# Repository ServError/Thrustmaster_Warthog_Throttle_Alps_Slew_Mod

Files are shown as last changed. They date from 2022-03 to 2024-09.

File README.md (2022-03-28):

# Thrustmaster Warthog Throttle Alps Slew Mod

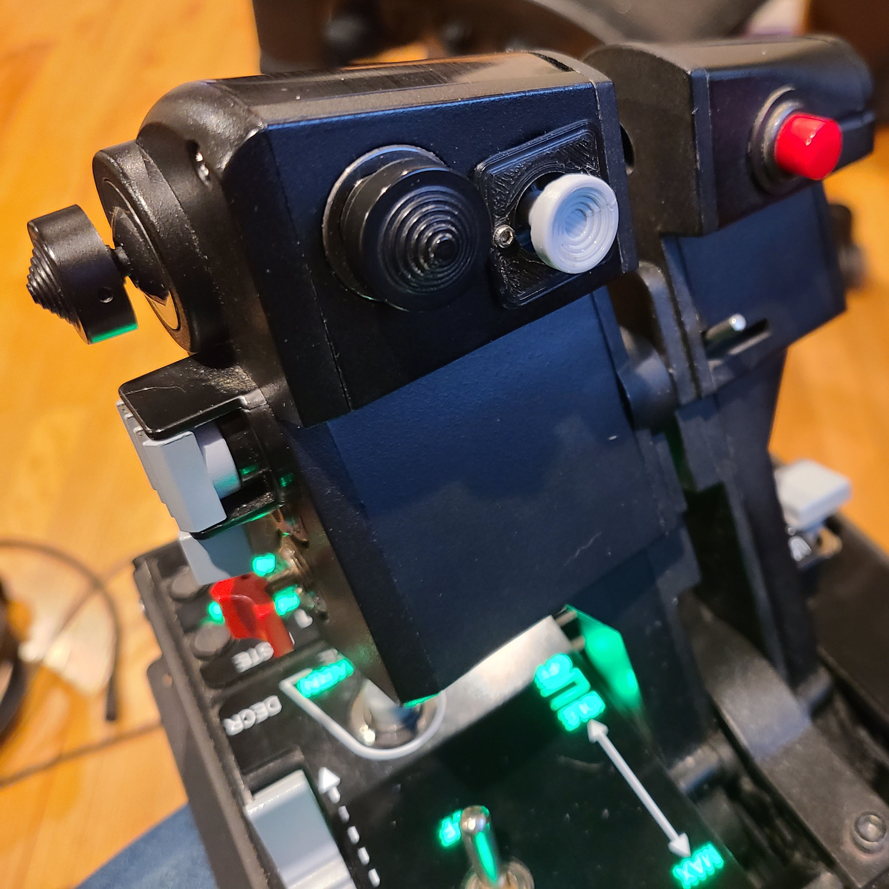
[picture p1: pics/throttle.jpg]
Mod


This repository houses the Thrustmaster Warthog Throttle Alps Slew Mod, an open source alternative to Thrustmaster's cheap slew joystick originally provided on the throttle.

## Is this Delta Sim's mod?

Nope, this was my 2022 mechanical, electrical, and software engineering practice project. Though the [Instructable](https://www.instructables.com/Thrustmaster-Warthog-Slew-Sensor-I2C-Upgrade/) provided a good sanity check, I started from scratch and did my own logic analysis, etc.

### Why does it look similar?

It's a bare minimum set of components fitting into a tight, keyed space while being compatible with an existing product, the only way it was going to look different was if I went out of my way to do something weird.

## How can I build it?

Let me start by stating the following: This project is mostly educational. Given the amount of parts and work it takes to build one of these, you should heavily consider buying [Delta Sim's slew mod](https://deltasimelectronics.com/products/thumbstick-slew-sensor-adapter) if you're just looking to mod your throttle and fly. Since (last I checked) it uses the same microcontroller as this project, you could even potentially switch to the firmware in this repository if you believed it to be beneficial.

### I'm still here

Alright then, You'll need to handle

- [The PCB](pcb/)
- [The Plastics](plastic/)
- [The Firmware](firmware/)

### Building

- Once the PCB is complete, program it with the firmware.

- Take 4 1.6x4mm screws and connect the frame to the PCB and take care to orient the notch correctly (see photo in plastics section).

- Connect the wire to the header.

- Unplug and pop out the original slew stick by pressing in the two clasps while pulling it outward.

- Insert the new unit into the throttle. Use notch on bottom of frame to align with notch in opening.

- Use 2 remaining screws to screw cover to frame. Do not overtighten! Screw in a good amount then install the stick.

- Check stick clearance with 2 screws and continue screwing until just barely clearing the stick.

- Connect the wire to the mainboard.

- Reassemble throttle while taking extreme care not to pinch cables between the plastic posts and throttle body. Feel free to wrap longer wires around the posts before assembling Use flashlight to triple verify clearance on other side before reinstall large screws.

- Plug in throttle and download [calibration tool with modified deadzone values](https://drive.google.com/file/d/1Ltr-QlWskVfA8-Oxs-A-aUs4HPpge5iv/view?usp=sharing). Run executable and follow instructions.

- Open Control Panel and verify stick behavior under Game Controllers.

### Drift correction / recalibration

- Download the calibration tool.

- Extract the files and edit A10_calibration.txt in a text editor.

- If the X axis is drifting, modify `Standard_DZ_SX = 0x05;` and increase 0x05 to something like 0x07. Remember to use hex values, not decimal (0x0A = 10, etc).

- Recalibrate using the exe.

- Check for drift. If still present, increase the value and calibrate again. Continue until no drift is present.

- Repeat for the Y axis by modifying `Standard_DZ_SY = 0x05;`

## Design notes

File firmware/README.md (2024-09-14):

# Firmware

The firmware was developed in Atmel/Microchip studio, and targets the ATTINY441 MCU. Originally, the project started on the ATTINY44A, but its multipurpose serial interface used for I2C didn't play well with the Warthog's I2C so I went with a pin compatible sister chip in order to avoid having to redesign my PCB.

## Flashing

If you just want to flash the MCU and get up and running, grab the hex file in the [Release](TM%20Warthog%20Alps%20Slew%20Mod/Release/) folder and flash it using your method of choice (one example provided below in [Windows Flashing Example](#windows-flashing-example-courtesy-of-stic)). I used a USBTinyISP and a DIP8 clip on the appropriate pins(rewired by jumping between the two ribbon cables) while supplying power over the main cable, but there are many flashers and connection methods at your disposal.

## Debugging

A debug header is present next to the main header and requires wires or a connector with 1.00mm spacing.

## Features

The firmware is focused around extremely low power consumption. The I2C peripheral handles communication while the processor is mostly asleep. It wakes up only to poll the joystick once between I2C polls, as well as to provide necessary I2C servicing.

# Windows Flashing Example (Courtesy of StiC)

### Programming the ATtiny 441 with a USBASP and AVRDUDE

First you’ll need a USBASP and a chip clip or socket to connect it to the ATtiny 441. They can be found on Amazon fairly cheaply.

https://www.amazon.ca/USBASP-Programmer-ATMEGA8-ATMEGA128-Support/dp/B07KK1CDQC

https://tinyurl.com/SOIC-Clip


USB ASP - bottom left  
Soic16 to dip16 socket - top left  
Soic16 clip - right

Next you’ll need AVRDUDE.

https://github.com/avrdudes/avrdude/releases

Extract it to a folder in the root directory. C:\AVRDUDE for example.

Open the [TM Warthog Alps Slew Mod/Release](TM%20Warthog%20Alps%20Slew%20Mod/Release) folder and open "TM Warthog Alps Slew Mod.hex". Download it using the 'Download raw file' button at the top right of the viewer.

Change the name of the downloaded file to something without spaces. “slew.hex” for example.
Move/copy it to the same folder as AVRDUDE.

Connect the VCC, RST, MOSI, MISO, SCK and GND from the USB ASP to the corresponding pins on the clip or socket. Use the Dark Blue bubbles (ISP interface) in the image to help locate the pins. Double check the connections before plugging in the USB ASP. Depending on the type of clip, a multimeter may be required to know which pin each wire is connected to. A socket would make this easier, but they can be more expensive.



Place the chip within the jaws of the clip. You may be able to place the chip pins down and just pick it up with the clip. Make sure the chip is in the right position and orientation. The small dot at the top of the chip indicates pin 1.

Plug the USB ASP into a USB port.

In Windows go to the search field in the lower left and type CMD. Select Command Prompt from the list.



In the command prompt window, type, or copy and paste, (without quotation marks) “cd\”, and hit Enter.
You should see C:\>



Type, “cd avrdude” if you followed my suggestion above.
You should see C:\AVRDUDE> 



Finally, type, “avrdude -c usbasp -p t441 -U flash:w:slew.hex” 
If you changed the hex file name to something else, use that instead of slew.



Hit Enter. Hopefully everything worked and no error messages appeared.

To program more, just put a new chip in the clip and tap the Up arrow on the keyboard and hit Enter. This will  repeat the last command in the Command Prompt window.

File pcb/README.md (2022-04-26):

# PCB

The PCB was designed in KiCAD and all project files are available in this repository for your tweaking pleasure.

## Ordering

For US based people, I recommend [OSH Park](https://oshpark.com/shared_projects/TJxoezw8) which can provide 3 boards for $4 to your door (which is insane!). Others will want to download the zip file from the [gerber_out](gerber_out/) folder and provide it to their PCB printing service of choice. It's possible that you'll need to download the KiCAD project and tweak the gerber settings if your printing service has any issues with the provided zip.

## Bill of Materials

| Part | Quantity | Example Link |
| --- |:---:| -----:|
| PCB | 1 | [link](https://oshpark.com/shared_projects/TJxoezw8) |
| ATTINY441 | 1 | [link](https://www.mouser.com/ProductDetail/556-ATTINY441-SSU) |
| 100nF cap | 1 | [link](https://www.mouser.com/ProductDetail/187-CL21B104KACNNNC) |
| 10k Ohm res | 1 | [link](https://www.mouser.com/ProductDetail/603-RC0805FR-0710KL) |
| Joystick | 1 | [link](https://www.mouser.com/ProductDetail/688-RKJXV122400R) |
| 1.6x4mm screw | 6 | [link](https://www.aliexpress.com/item/32968483467.html) |
| 15cm 5P cable | 1 | [link](https://www.aliexpress.com/item/32979005732.html) |
| 5P 1.25mm Header | 1 | [link](https://www.aliexpress.com/item/1005003115054198.html) |

If using the example link for the header, select the 'DIP' variety (they mean thru-hole, but oh well).

## Assembly

It's perfectly possible to construct the entire board with a soldering iron, but is certainly more convenient to install the microcontroller and passives using hot air.

If your PCB was delivered with excess material near the header side, I'd recommend filing it down for a cleaner fit.

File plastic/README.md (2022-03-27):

# Plastics

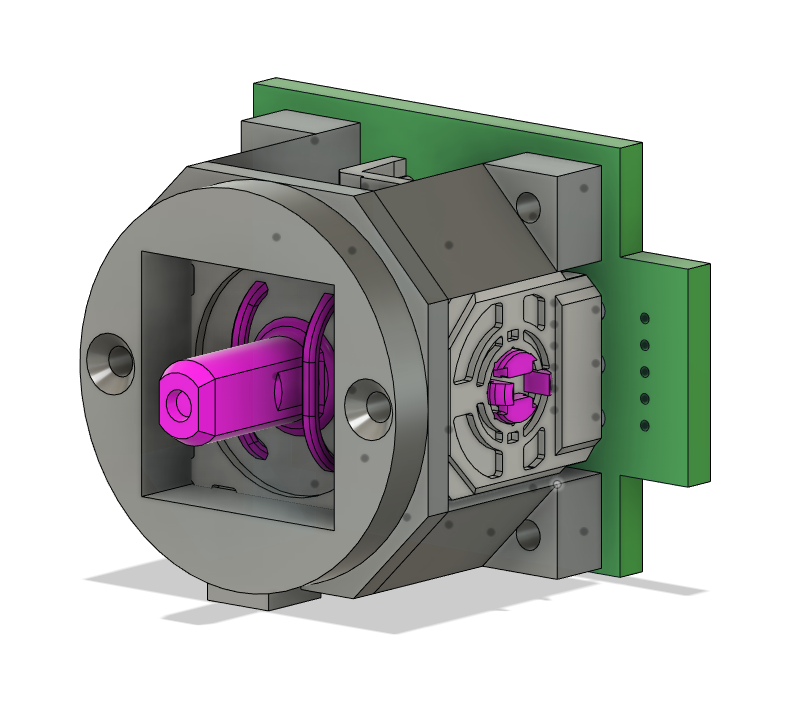
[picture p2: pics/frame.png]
frame


All plastics were designed in Fusion 360, and appropriate archive files have been uploaded.

## Printing

To print, download all 4 STL files and feed them into your slicer of choice. You can use an online printing service, but be aware of the warning below.

### Warning!

These parts were originally designed with ABS shrinkage in mind, and before uploading were rescaled (to 95.3%) for PETG based on some test runs. You may need to tweak the scaling to get a good fit across all your parts.

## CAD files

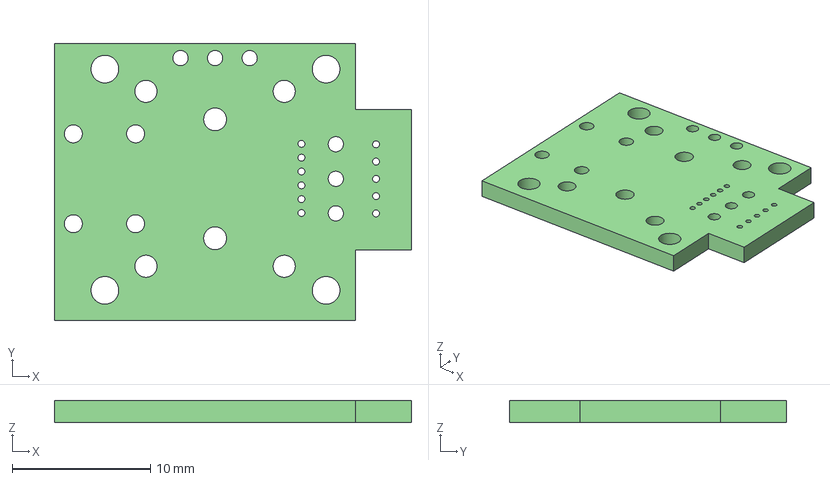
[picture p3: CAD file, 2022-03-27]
pcb/TM_Warthog_Open_Analog_Slew.step
25.8 x 20.0 x 1.60 mm

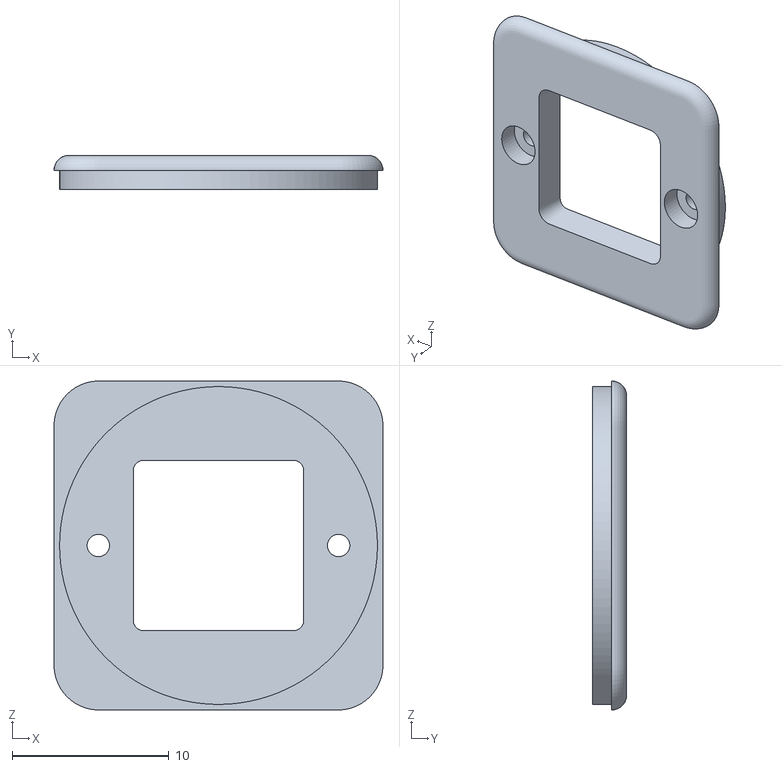
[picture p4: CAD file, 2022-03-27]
plastic/Warthog_Slew_Square_Cover_v14.stl
21.0 x 2.19 x 21.0

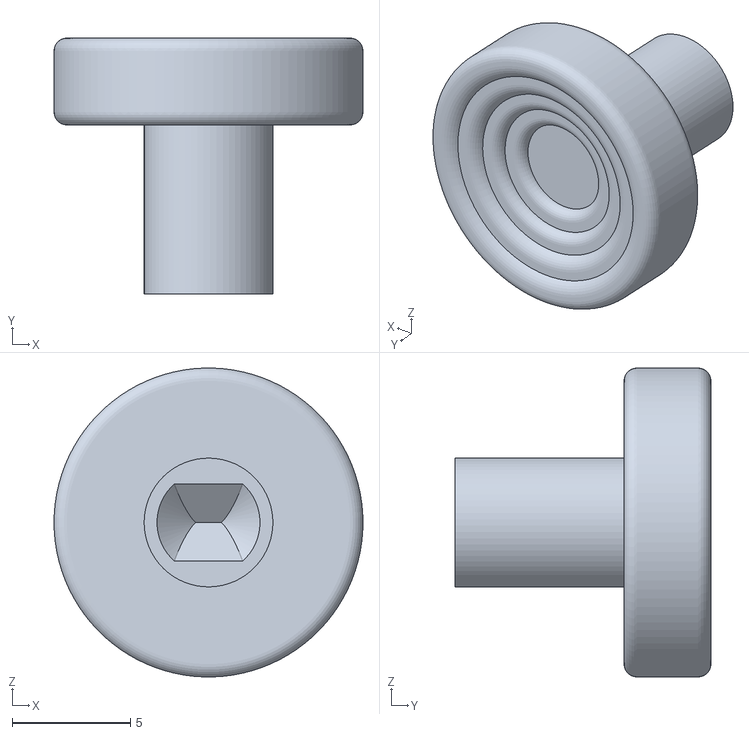
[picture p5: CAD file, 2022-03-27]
plastic/Warthog_Slew_Stick_v11.stl
13.1 x 10.8 x 13.1

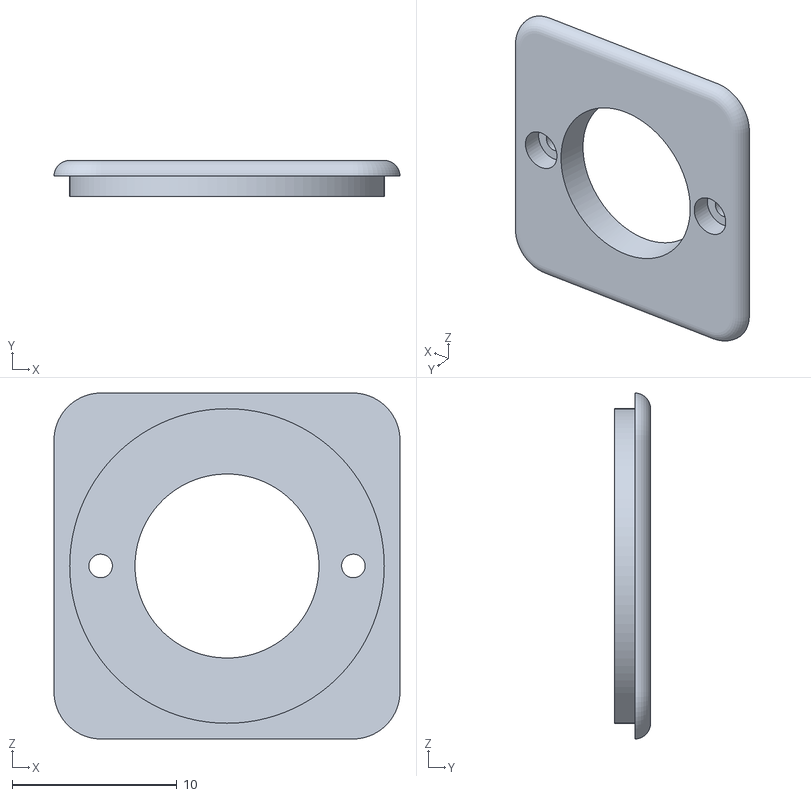
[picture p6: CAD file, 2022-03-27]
plastic/Warthog_Slew_Round_Cover_v13.stl
21.0 x 2.19 x 21.0

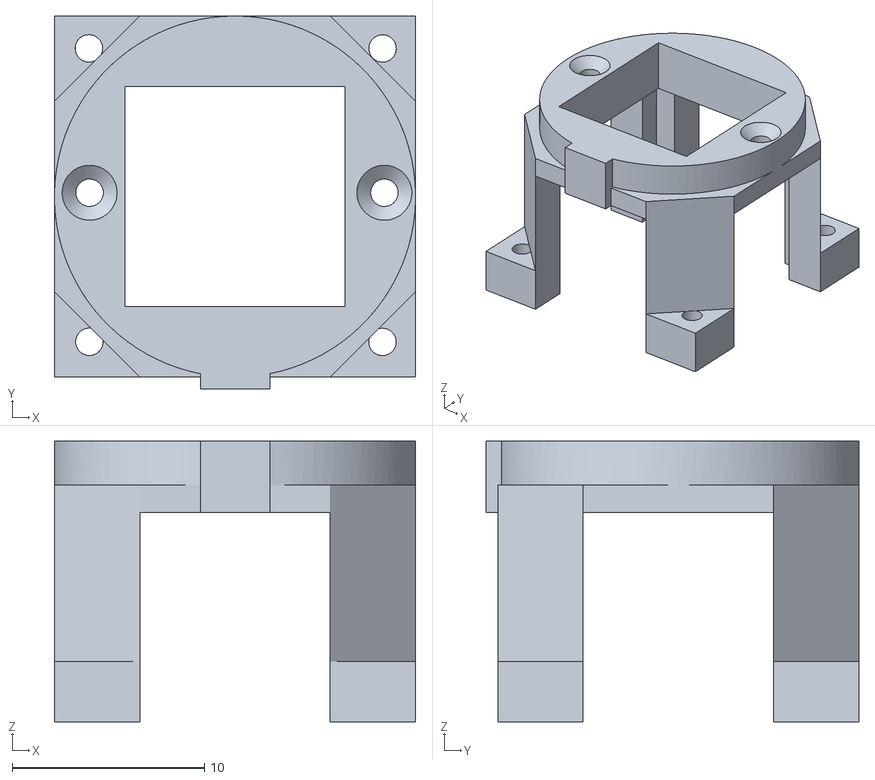
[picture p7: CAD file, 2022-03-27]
plastic/Warthog_Slew_Frame_v14.stl
18.8 x 19.4 x 14.6

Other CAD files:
plastic/Warthog Slew Frame v14.f3d
plastic/Warthog Slew Round Cover v13.f3d
plastic/Warthog Slew Square Cover v14.f3d
plastic/Warthog Slew Stick v11.f3d

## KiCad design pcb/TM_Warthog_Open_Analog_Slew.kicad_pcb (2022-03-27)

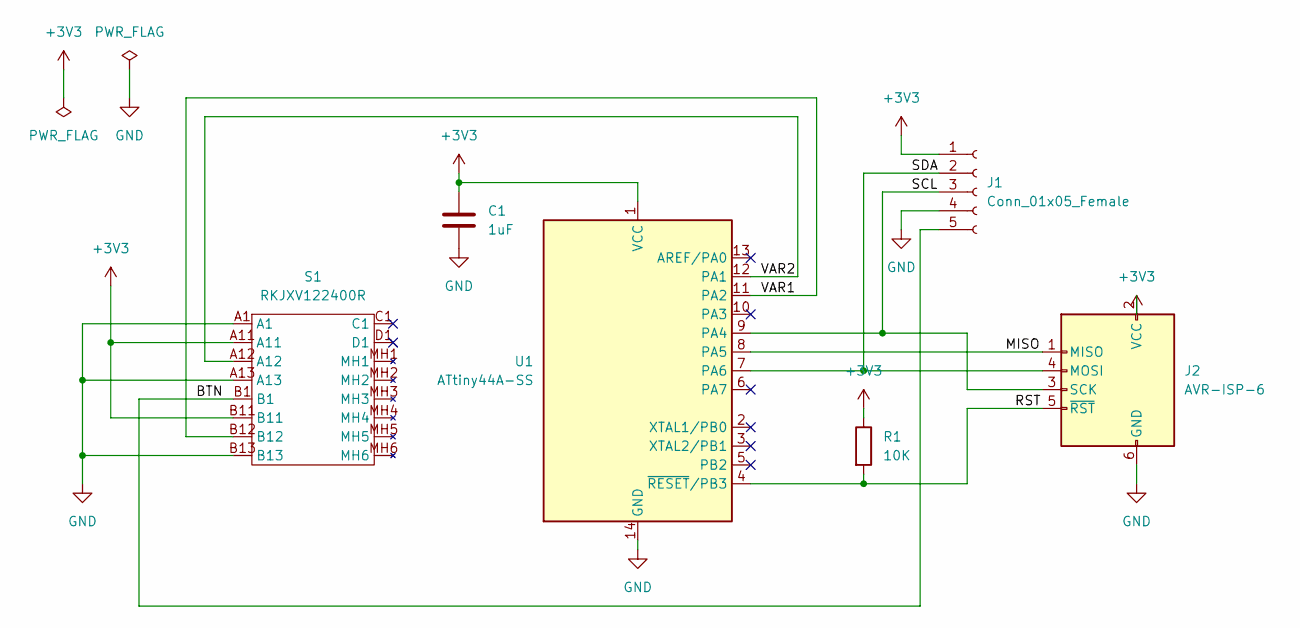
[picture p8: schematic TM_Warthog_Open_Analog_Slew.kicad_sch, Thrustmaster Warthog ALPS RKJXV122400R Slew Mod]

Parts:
C1: 1uF; C_0805_2012Metric
J1: Conn_01x05_Female; Molex_PicoBlade_53047-0510_1x05_P1.25mm_Vertical
J2: AVR-ISP-6; PinHeader_1x06_P1.00mm_Vertical
R1: 10K; R_0805_2012Metric
S1: RKJXV122400R
U1: ATtiny44A-SS; SOIC-14_3.9x8.7mm_P1.27mm

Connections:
+3V3: C1.1, J1.1, J2.2 (VCC), R1.1, S1.A11, S1.B11, U1.1 (VCC)
/BTN: J1.5, S1.B1
/MISO: J2.1 (MISO), U1.8 (PA5)
/RST: J2.5 (~RST), R1.2, U1.4 (~RESET/PB3)
/SCL: J1.3, J2.3 (SCK), U1.9 (PA4)
/SDA: J1.2, J2.4 (MOSI), U1.7 (PA6)
/VAR1: S1.B12, U1.11 (PA2)
/VAR2: S1.A12, U1.12 (PA1)
GND: C1.2, J1.4, J2.6 (GND), S1.A1, S1.A13, S1.B13, U1.14 (GND)

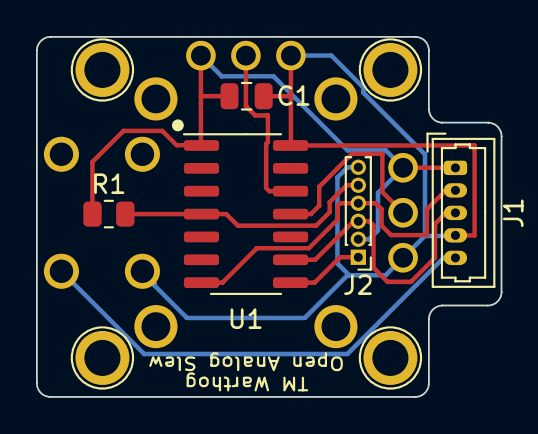
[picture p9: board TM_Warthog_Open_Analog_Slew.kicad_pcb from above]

Board: 2 copper layers, 25.8 x 20.0 mm, 6 parts (1 on the bottom side), 9 nets.

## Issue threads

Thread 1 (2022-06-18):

main.c:14:10: fatal error: xc.h: No such file or directory

moricef, 2022-06-18:
Hi, and thank you for your work.
I'm not a great programmer and I tried since several weeks hardly to make a I2C slave code with arduino IDE based on the I2C master code by Mike Hord from SparkFun for the AMS N35P112 (http://cdn.sparkfun.com/datasheets/BreakoutBoards/EasyPoint_Demo.ino) and having read, not all,  the N35P112 datasheet. But I have somes difficulty with the Wire library and the slave handlers.
And tonight, I find your project ...
So I try to compile it with Geany under Linux, but there is that fatal error with that included header xc.h
I have installed all the necessary for the avr-c with linux : avrdude gcc-avr avr-libc

ServError, 2022-06-21:
This project was built in Microchip Studio with the XC8 toolchain, which your setup lacks and therefor errors out.

You can most likely replace the line including xc.h and instead include avr/io.h and build in your current environment.

moricef, 2022-06-25:
Thanks. It's ok now.
Would you be able to detail your code explanations in the comments in order to make it more understandable for non-experts like me. For an educational purpose.
For example, why the files Twi_slave.h and Twi_slave.c (AVR290: Avoid Clock Stretch with Tiny AVR)?
Or even the whole preparation part of the registers of the attany44, (ADC, Pull-up resistances, timers, interruptions, etc.)

Shawnb03, 2022-12-18:
I am completely lost to what I need to do to program the attiny441 IC. Could you please guide me on what I need to do to program it. I have all the other parts listed except for the PCB and those come in on the 21st. Your help would be greatly appreciated.

ServError, 2023-01-07:
> I am completely lost to what I need to do to program the attiny441 IC. Could you please guide me on what I need to do to program it. I have all the other parts listed except for the PCB and those come in on the 21st. Your help would be greatly appreciated.

Hi. Please don't append new issues to someone else's existing closed issue, the chance of it being seen is slim. If you're still having trouble, open a new issue. Thanks.

Closed 2022-06-25.

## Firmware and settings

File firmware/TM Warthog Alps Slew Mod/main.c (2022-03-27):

/**
 * brief ATTiny441 ADC read 2 channels to TWI module as I2C slave
 *
 * Created: 1/23/2022 10:01:07 PM
 *  Author: ServError
 */

#ifndef F_CPU
#define F_CPU 8000000
#endif

//#define PB1_DEBUG

#include <xc.h>
#include "avr/interrupt.h"
#include "avr/sleep.h"

#include "twi_slave.h"
#include "timer1.h"

uint8_t command; 
int8_t x_ready;
int8_t y_ready;
uint8_t sleep_with_timer = 0;
uint8_t sleep_when_idle = 0;
uint8_t wake_source_timer1 = 0;

uint8_t state = 0;

void adc_setup(void)
{
	// Set pin direction to input and turn off pull-ups
	DDRA &= ~((1 << ADC1D) | (1 << ADC2D));
	PORTA &= ~((1 << ADC1D) | (1 << ADC2D));
	
	ADMUXA |= (0b0001 << MUX0);  // select ADC channel 1 (PA1)
	ADMUXB &= 0x00;              // Select VCC reference (3.3V) and 1x Gain
	ADCSRA |= (1 << ADEN);       // Enable the ADC module
	ADCSRA |= (0b100 << ADPS0);  // Enable ADC with Clock prescaled by 16 ; If Clock speed is 8MHz, then ADC clock =
	// 8MHz/16 = 500kHz
	DIDR0  |= ((1 << ADC2D) | (1 << ADC1D)); // Disable digital inputs for ADC pins to save power
}

void adc_sleep(void)
{
	ADCSRA &= ~(1 << ADEN);      // Disable the ADC module	
}

void adc_wake(void)
{
	ADCSRA |= (1 << ADEN);       // Enable the ADC module	
}

uint16_t adc_single_conversion(uint8_t channel)
{
	uint16_t adcResult;
	
	if (channel < 1) return 0; // channel not allowed in this configuration

	ADMUXA &= 0x00; // Clear channel selection
	ADMUXA |= (1 << (channel - 1));  // set ADC channel
	ADCSRA |= (1 << ADSC); // start a single conversion

	while ((ADCSRA & (1 << ADSC)) != 0)
	;                      // Wait till conversion is complete
	adcResult = ADCW;      // Read the ADC result

	return adcResult;
}

void twi_data_from_master(uint8_t data)
{
	command = data;
	sleep_when_idle = 1;
}

uint8_t twi_data_to_master(void)
{
	uint8_t data_to_master;
	
	switch (command)
	{
		case 0x10:
			data_to_master = x_ready;
			break;
		case 0x11:
			data_to_master = y_ready;
			break;
		case 0x0F:
			data_to_master = 0xF1;
			break;
		default:
			data_to_master = 0x00;
			break;
	}
	
	sleep_when_idle = 1;
	
	return data_to_master;
}

void twi_stop_callback(void)
{
	sleep_with_timer = 1; // Set a flag to go to sleep once back in main loop
}

void twi_address_callback(void)
{
	sleep_when_idle = 1;
}

void timer1_callback(void)
{
	wake_source_timer1 = 1;
}

inline void debug_pb1_high(void)
{
#ifdef PB1_DEBUG
	PORTB |= (1 << PORTB1);
#endif
}

inline void debug_pb1_low(void)
{
#ifdef PB1_DEBUG
	PORTB &= ~(1 << PORTB1);
#endif
}

int main(void)
{
	int8_t x_conv, y_conv;

	CCP = 0xD8; // write access signature to Configuration Change Protection Register. Might be redundant
	CLKPR = 0;  // Force clock to 8MHz
	
	MCUCR = (0 << SM1) | (0 << SM0) | (0 << SE); // Idle Sleep Mode
	
	// Set unterminated pins as pulled up inputs

#ifdef PB1_DEBUG
	DDRB &= ~((1 << PORTB0) | (1 << PORTB2));
	PUEB |= ((1 << PUEB0) | (1 << PUEB2));
	// Set up PORTB2 for debug
	DDRB |= (1 << PORTB1);
#else
	DDRB &= ~((1 << PORTB0) | (1 << PORTB1) | (1 << PORTB2));
	PUEB |= ((1 << PUEB0) | (1 << PUEB1) | (1 << PUEB2));
#endif
	DDRA &= ~((1 << PORTA0) | (1 << PORTA3) | (1 << PORTA5) | (1 << PORTA7));
	PUEA |= ((1 << PUEA0) | (1 << PUEA3) | (1 << PUEA5) | (1 << PUEA7));
	
	// Leave ADC, TWI, and Timer1 peripherals enabled
	PRR =  (1<<PRUSART0) | (1<<PRUSART0) | (1<<PRSPI) | (1<<PRTIM2) | (1<<PRTIM0); // Disable unused peripherals
	
	adc_setup();

	// Unnecessary, but explicitly set TWI pins as inputs, no pull
	DDRA &= ~((1 << PORTA4) | (1 << PORTA6));
	PUEA &= ~((1 << PUEA4) | (1 << PUEA6));
	
	/* initialize TWI Slave */
	twi_slave_initialise();
	
	// Setup Timer 1
	timer1_setup();

	// Enable interrupts
	sei();

	while(1)
	{
		debug_pb1_low(); // Drive low while awake
		
		if (wake_source_timer1 == 1)
		{
			wake_source_timer1 = 0;
			
			adc_wake();
			x_conv = (-1 * (int8_t)(adc_single_conversion(PINA1) / 4)) + 127;
			y_conv = (int8_t)(adc_single_conversion(PINA2) / 4) - 128;
			
			x_ready = x_conv;
			y_ready = y_conv;

			adc_sleep();
			// Now that we've polled the joystick, we can sleep until the TWI address match interrupt wakes us
			debug_pb1_high(); // Drive high while asleep
			sleep_mode();
		}
		
		if (sleep_with_timer == 1)
		{
			// Configure to sleep and only poll each channel once about 4.5ms after the sending of y axis data completes
			sleep_with_timer = 0;
			
			timer1_set_4_5_usec();
			timer1_start();

			debug_pb1_high(); // Drive high while asleep
			sleep_mode();
		}
		else if (sleep_when_idle == 1)
		{
			sleep_when_idle = 0;
			debug_pb1_high(); // Drive high while asleep
			sleep_mode();
		}
	}
	return 0;
}
